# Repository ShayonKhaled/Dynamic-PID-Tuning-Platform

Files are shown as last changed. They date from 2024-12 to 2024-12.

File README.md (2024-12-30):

# **Dynamic PID Tuning Platform**


## **Overview**

The **Dynamic PID Tuning Platform** is a user-friendly test rig built to make PID tuning easier for robotics projects. It’s specifically designed for tuning the PID settings of DJI Robomaster M3508 P19 motors, which are controlled using C620 ESCs via the CAN protocol.

With this platform, you can easily adjust PID parameters and monitor real-time feedback on setpoints, motor speed (RPM), and control outputs. The data is displayed on an onboard LCD and can also be visualized using an external Python-based software for more detailed analysis.

Watch this video to see it in action:

https://github.com/user-attachments/assets/ace8c13b-92a7-4c02-9562-aeda0b1e9ec8

---

## **Features**
- **Real-time PID Tuning:** Adjust P, I, and D values using rotary encoders.
- **CAN Bus Communication:** Sends control data to Robomaster C620 ESCs.
- **Live Monitoring:** Displays motor speed, setpoint, and PID outputs on a 20x4 LCD display.
- **External Visualization:** Outputs CSV-formatted data to a Python-based GUI for graphing and analysis.

### **Limitations**
- At this time, the code supports controlling only **one motor** at a time.

---

## **Hardware Components**
- **Freenove ESP32 Dev Board** (or any ESP32 board)
- **Robomaster C620 ESC** and **M3508 P19 Motor**
- **MCP2515 CAN module**
- **KY-040 Rotary Encoders** (4x for P, I, D, and setpoint)
- **20x4 LCD Display** with I2C Backpack (PCF8574)

### **Recommended Wiring**
For easier connections, it is recommended to use a Freenove ESP32 breakout board. You can also build the circuit on a breadboard if necessary. Using an external 5V power source for peripherals is highly recommended.

---

## **Pin Connections**

| **Component** | **Pin on Component** | **Pin on ESP32**  |
|---|---|---|
| MCP2515 CAN Module | CS | GPIO 5 |
| | INT | GPIO 15 |
| KY-040 Encoder (P) | CLK | GPIO 35 |
| | DT | GPIO 32 |
| KY-040 Encoder (I) | CLK | GPIO 25 |
| | DT | GPIO 33 |
| KY-040 Encoder (D) | CLK | GPIO 27 |
| | DT | GPIO 26 |
| KY-040 Encoder (Setpoint) | CLK | GPIO 39 |
| | DT | GPIO 34 |
| 20x4 LCD Display with I2C | SDA | GPIO 21 |
| | SCL | GPIO 22 |

---

## **Software Features**
### **ESP32 Firmware**
- Written in Arduino framework using PlatformIO.
- Implements PID control logic with:
  - Adjustable P, I, D values using rotary encoders.
  - Real-time CAN communication with the C620 ESC.
  - CSV-formatted serial data output for visualization.
  


### **Python Visualization Tool**
- Plots real-time graphs of:
  - Motor RPM
  - Setpoint
  - PID output
- Provides GUI controls for serial port selection.

---

## **Setup Instructions**
1. **Hardware Setup:**
   - Connect all components as per the pin connections table.
   - Use an external 5V power source for the MCP2515 module and the LCD to ensure stability.

2. **Software Setup:**
   - Install PlatformIO extension on Visual Studio Code if you haven't already.
   - Clone this repository:
     ```bash
     git clone https://github.com/ShayonKhaled/Dynamic-PID-Tuning-Platform.git
     ```
   - Open the project in PlatformIO and upload the firmware to your ESP32.

3. **Python Visualization:**
   - Install required Python libraries:
     ```bash
     pip install matplotlib pyserial tkinter
     ```
   - Run the Python script for real-time graphing:
     ```bash
     python3 pidVisualizer.py
     ```
   - Select the serial port of your ESP32 from the drop down menu and hit the connect button. The ESP32 must be connected to your computer.
   
   

  

---

## **Notes**
- **Power Supply:** Avoid drawing power for the MCP2515 and LCD display directly from the ESP32. Use a separate 5V supply to prevent voltage drops and ensure reliable operation.
- **Freenove ESP32 Breakout Board:** The breakout board simplifies wiring but is not mandatory.

---

## **Building the DIN Rail Test Rack**

To house the components and provide a modular design, I used **4X 250mm DIN rails** to build the test rack. The stands for the rails were designed by **PlasticXYZ** and can be found here: [DIN Rail Test Rack Stands by PlasticXYZ](https://www.printables.com/model/150786-din-rail-test-rack).

### **Custom Mount Designs**
I designed custom mounts for the following components:
- **Freenove ESP32 Breakout Board**
- **MCP2515 CAN Transceiver Module**
- **Rotary Encoders**
- **20x4 LCD**

These designs are included in the **"3D Printables"** folder in both **.STL** and **.STEP** formats. You can choose to:
1. **Bolt the mounts directly onto the DIN rail**, or
2. **Use DIN clips** (designed by PlasticXYZ) to attach them. The DIN clips can be mounted or unmounted easily from the DIN rails. You can find the DIN clips design here: [DIN Rail Clip by PlasticXYZ](https://www.printables.com/model/161740-din-rail-clip).

### **Mounting Specifications**
- **Mounting Holes:** 18mm apart. These can be modified using the provided `.STEP` files if needed.
- **Fasteners Used:**
  - **Modules:** Mounted with self-tapping screws.
  - **DIN Clips:** Mounted with M3 bolts (6mm length).
- **No Heat Press Inserts:** The mounts were specifically designed for simplicity, and all components are secured with self-tapping screws or bolts.

This setup provides a sturdy, modular, and customizable framework for the PID tuning platform, making it easy to assemble, modify, and expand as needed.

## **License**
This project is licensed under the GNU General Public License v3.0 License. See the [LICENSE](LICENSE) file for details.

---

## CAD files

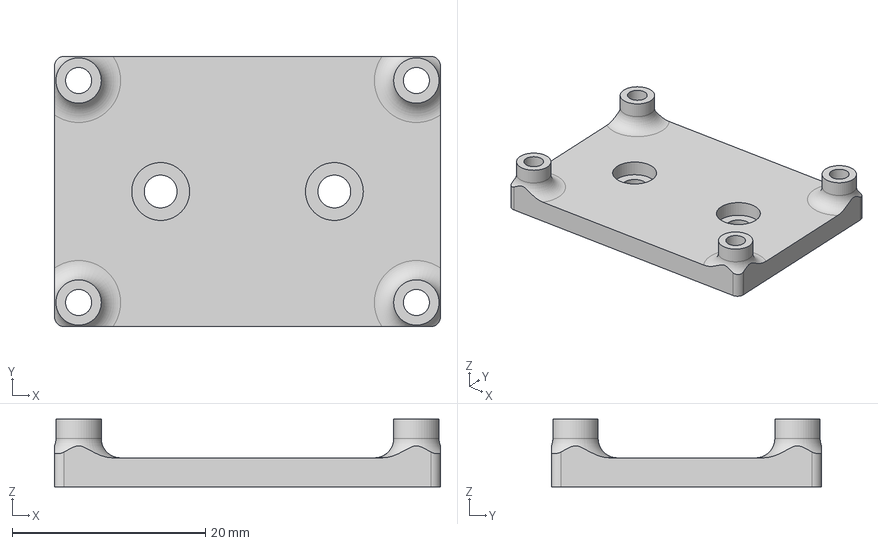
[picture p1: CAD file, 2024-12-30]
3D Printables/STEP files/MCP2515 CAN DIN Mount.step
40.0 x 28.0 x 7.00 mm

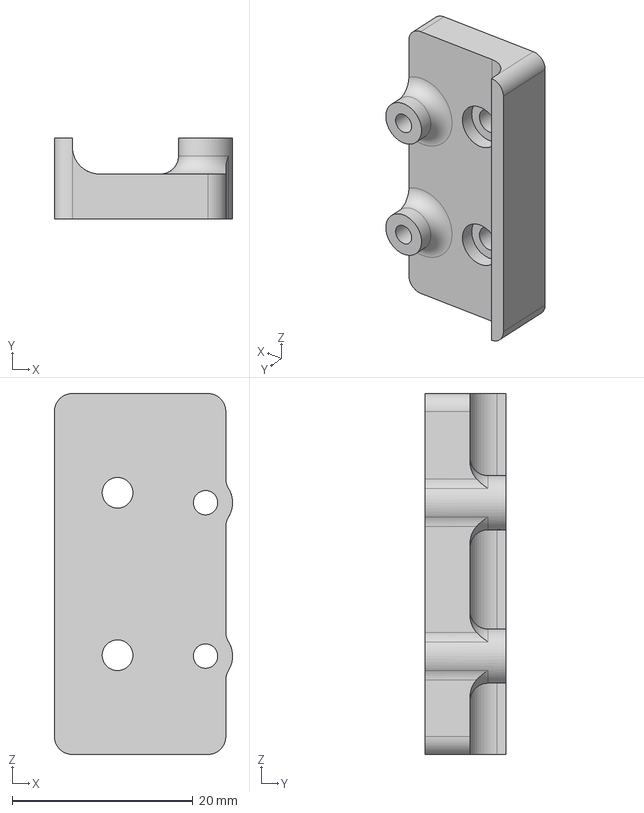
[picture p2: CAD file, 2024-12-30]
3D Printables/STEP files/KY-040 Rotary Encoder DIN Mount.step
19.7 x 9.00 x 40.0 mm

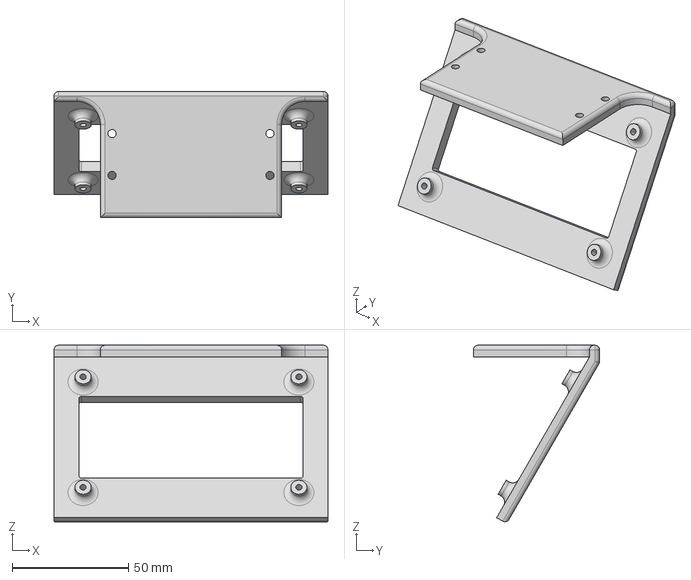
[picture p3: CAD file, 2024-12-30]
3D Printables/STEP files/2004 LCD Mount DIN Mount.step
118.0 x 54.3 x 76.0 mm

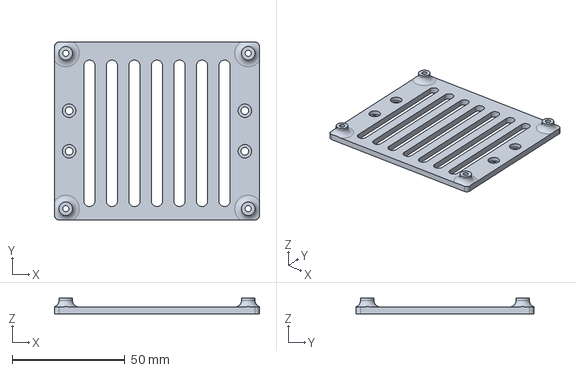
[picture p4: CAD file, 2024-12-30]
3D Printables/STEP files/Freenove ESP32 DIN Mount.step
91.0 x 79.0 x 7.05 mm

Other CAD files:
3D Printables/STL Files/2004 LCD Mount DIN Mount.stl
3D Printables/STL Files/Freenove ESP32 DIN Mount.stl
3D Printables/STL Files/KY-040 Rotary Encoder DIN Mount.stl
3D Printables/STL Files/MCP2515 CAN DIN Mount.stl

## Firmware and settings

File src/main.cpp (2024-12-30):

#include "config.h"
#include "encoder.h"
#include "lcd_control.h"
#include "can_comm.h"
#include "pid_control.h"

#define pidStepSize 0.001
#define setpointStepSize 500

void setup()
{
    Serial.begin(115200);

    initLCD();
    initCAN();


    pinMode(encoderPA, INPUT_PULLUP);
    pinMode(encoderPB, INPUT_PULLUP);
    pinMode(encoderIA, INPUT_PULLUP);
    pinMode(encoderIB, INPUT_PULLUP);
    pinMode(encoderDA, INPUT_PULLUP);
    pinMode(encoderDB, INPUT_PULLUP);
    pinMode(encoderSetpointA, INPUT_PULLUP);
    pinMode(encoderSetpointB, INPUT_PULLUP);
    pinMode(canInt, INPUT);

    attachInterrupt(digitalPinToInterrupt(encoderPA), handlePEncoder, CHANGE);
    attachInterrupt(digitalPinToInterrupt(encoderPB), handlePEncoder, CHANGE);
    attachInterrupt(digitalPinToInterrupt(encoderIA), handleIEncoder, CHANGE);
    attachInterrupt(digitalPinToInterrupt(encoderIB), handleIEncoder, CHANGE);
    attachInterrupt(digitalPinToInterrupt(encoderDA), handleDEncoder, CHANGE);
    attachInterrupt(digitalPinToInterrupt(encoderDB), handleDEncoder, CHANGE);
    attachInterrupt(digitalPinToInterrupt(encoderSetpointA), handleSetpointEncoder, CHANGE);
    attachInterrupt(digitalPinToInterrupt(encoderSetpointB), handleSetpointEncoder, CHANGE);


    delay(1000);
    lcd.clear();
    lcd.setCursor(1, 1);
    lcd.print("Dynamic PID Tuning");
    lcd.setCursor(6, 2);
    lcd.print("Platform");
    delay(2000);
    lcd.clear();
}

void loop()
{
    static unsigned long lastUpdate = 0;
    unsigned long currentMillis = millis();

    
    // Read from the designated kP kI kD encoders and multiply them by pidStepSize to allow smaller steps
    pVal = P_count * pidStepSize;
    iVal = I_count * 0.0001;
    dVal = D_count * pidStepSize;
    setpointVal = constrain(setpoint_count * setpointStepSize, 0, 9000);

    short rpm = receiveRPM(); //receive RPM from the encoder of the motor
    currentSpeed = (rpm == 0) ? 0 : rpm; //if RPM is not 0, copy the value to currentSpeed

    float controlOutput = computePID(setpointVal, currentSpeed); //Run the setpoint and current speed through the contrl loop

    short controlSpeed = (short)controlOutput; // Cast to short for CAN message

    //sending higher order byte and lower order byte of the speed to the first motor on the CAN Bus.
    byte data[8] = {controlSpeed >> 8, controlSpeed, 0x00, 0x00, 0x00, 0x00, 0x00, 0x00}; 
    sendCANMessage(0x200, data, 8); //message ID for the first 4 motors is 0x200 according to the DJI C620 manual



    // sending the data in CSV format for the Python program to read
    Serial.print("Setpoint:");
    Serial.print(setpointVal); 
    Serial.print(",RPM:");
    Serial.print(currentSpeed); 
    Serial.print(",PID:");
    Serial.print(controlOutput);
    Serial.print(",P:");
    Serial.print(pVal);
    Serial.print(",I:");
    Serial.print(iVal); 
    Serial.print(",D:");
    Serial.println(dVal); 

    if (currentMillis - lastUpdate >= 100)
    {
        lastUpdate = currentMillis;
        updateLCD(); // update LCD every 100 milliseconds
    }
}

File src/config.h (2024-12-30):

#ifndef CONFIG_H
#define CONFIG_H

#include <Wire.h>
#include <LiquidCrystal_I2C.h>
#include <Arduino.h>

// LCD configuration
#define lcdColumn 20
#define lcdRow 4
#define lcdAddress 0x27

// Declare the LCD object for global access
extern LiquidCrystal_I2C lcd;

// Encoder pin definitions
#define encoderPA 35
#define encoderPB 32
#define encoderIA 25
#define encoderIB 33
#define encoderDA 27
#define encoderDB 26
#define encoderSetpointA 39
#define encoderSetpointB 34


#define canCsPin 5
#define canInt 15


// Declare global variables
extern volatile int P_count, I_count, D_count, setpoint_count;
extern volatile int P_lastState, I_lastState, D_lastState, setpoint_lastState;
extern short currentSpeed;

extern float pVal, iVal, dVal, setpointVal;
extern bool showText;

#endif 

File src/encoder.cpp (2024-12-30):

#include "encoder.h"
#include "config.h"

void IRAM_ATTR handlePEncoder()
{
  // read the state of the encoder pins
  int A = digitalRead(encoderPA);
  int B = digitalRead(encoderPB);
  int currentState = (A << 1) | B;

  // check if the encoder is rotating clockwise
  if ((P_lastState == 0b00 && currentState == 0b01) ||
      (P_lastState == 0b01 && currentState == 0b11) ||
      (P_lastState == 0b11 && currentState == 0b10) ||
      (P_lastState == 0b10 && currentState == 0b00))
  {
    P_count++;
  }
  // check if the encoder is rotating counterclockwise
  else if ((P_lastState == 0b00 && currentState == 0b10) ||
           (P_lastState == 0b10 && currentState == 0b11) ||
           (P_lastState == 0b11 && currentState == 0b01) ||
           (P_lastState == 0b01 && currentState == 0b00))
  {
    P_count--;
  }
  // update the last state
  P_lastState = currentState;
}

void IRAM_ATTR handleIEncoder()
{
  // read the state of the encoder pins
  int A = digitalRead(encoderIA);
  int B = digitalRead(encoderIB);
  int currentState = (A << 1) | B;

  // check if the encoder is rotating clockwise
  if ((I_lastState == 0b00 && currentState == 0b01) ||
      (I_lastState == 0b01 && currentState == 0b11) ||
      (I_lastState == 0b11 && currentState == 0b10) ||
      (I_lastState == 0b10 && currentState == 0b00))
  {
    I_count++;
  }
  // check if the encoder is rotating counterclockwise
  else if ((I_lastState == 0b00 && currentState == 0b10) ||
           (I_lastState == 0b10 && currentState == 0b11) ||
           (I_lastState == 0b11 && currentState == 0b01) ||
           (I_lastState == 0b01 && currentState == 0b00))
  {
    I_count--;
  }
  // update the last state
  I_lastState = currentState;
}

void IRAM_ATTR handleDEncoder()
{
  // read the state of the encoder pins
  int A = digitalRead(encoderDA);
  int B = digitalRead(encoderDB);
  int currentState = (A << 1) | B;

  // check if the encoder is rotating clockwise
  if ((D_lastState == 0b00 && currentState == 0b01) ||
      (D_lastState == 0b01 && currentState == 0b11) ||
      (D_lastState == 0b11 && currentState == 0b10) ||
      (D_lastState == 0b10 && currentState == 0b00))
  {
    D_count++;
  }
  // check if the encoder is rotating counterclockwise
  else if ((D_lastState == 0b00 && currentState == 0b10) ||
           (D_lastState == 0b10 && currentState == 0b11) ||
           (D_lastState == 0b11 && currentState == 0b01) ||
           (D_lastState == 0b01 && currentState == 0b00))
  {
    D_count--;
  }
  // update the last state
  D_lastState = currentState;
}

void IRAM_ATTR handleSetpointEncoder()
{
    // read the state of the encoder pins
    int A = digitalRead(encoderSetpointA);
    int B = digitalRead(encoderSetpointB);
    int currentState = (A << 1) | B;

    // check if the encoder is rotating clockwise
    if ((setpoint_lastState == 0b00 && currentState == 0b01) ||
        (setpoint_lastState == 0b01 && currentState == 0b11) ||
        (setpoint_lastState == 0b11 && currentState == 0b10) ||
        (setpoint_lastState == 0b10 && currentState == 0b00))
    {
        // increment only if below the upper limit
        if (setpoint_count < 9000)
        {
            setpoint_count++;
        }
        else {return;}
    }
    // check if the encoder is rotating counterclockwise
    else if ((setpoint_lastState == 0b00 && currentState == 0b10) ||
             (setpoint_lastState == 0b10 && currentState == 0b11) ||
             (setpoint_lastState == 0b11 && currentState == 0b01) ||
             (setpoint_lastState == 0b01 && currentState == 0b00))
    {
        // decrement only if above the lower limit
        if (setpoint_count > 0)
        {
            setpoint_count--;
        }
        else {return;}
    }

    // update the last state
    setpoint_lastState = currentState;
}

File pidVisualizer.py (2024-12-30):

import matplotlib
matplotlib.use("TkAgg")  # Use TkAgg backend for compatibility on macOS

import serial
import serial.tools.list_ports
import matplotlib.pyplot as plt
from matplotlib.animation import FuncAnimation
from matplotlib.backends.backend_tkagg import FigureCanvasTkAgg
import tkinter as tk
from tkinter import StringVar, OptionMenu

# Global variables for serial connection
ser = None
baudRate = 115200
dataPoints = 100  # Number of points to display on the graph

# Data storage
rpmData = []
setpointData = []
pidData = []

# Labels for real-time values
pValue = None
iValue = None
dValue = None
setpointValue = None
currentSpeed = None
controlOutput = None

# Function to list available serial ports
def getSerialPorts():
    ports = serial.tools.list_ports.comports()
    return [port.device for port in ports]

# Function to start the serial connection
def startConnection(selectedPort, statusLabel, disconnectButton):
    global ser
    try:
        ser = serial.Serial(selectedPort, baudRate, timeout=1)
        statusLabel.config(text=f"Connected to {selectedPort}", fg="lightgreen")
        disconnectButton.config(state="normal")  # Enable the disconnect button
    except Exception as e:
        statusLabel.config(text=f"Failed to connect: {e}", fg="red")

# Function to disconnect the serial connection
def disconnectConnection(statusLabel, disconnectButton):
    global ser
    if ser and ser.is_open:
        ser.close()
        ser = None
        statusLabel.config(text="Disconnected", fg="red")
        disconnectButton.config(state="disabled")  # Disable the disconnect button

# Function to update the graph and all displayed values
def updateGraph(frame, pValue, iValue, dValue, setpointValue, currentSpeed, controlOutput):
    global rpmData, setpointData, pidData, ser

    if ser and ser.is_open:
        try:
            line = ser.readline().decode('utf-8').strip()
            if line:
                # Parse data (e.g., Setpoint:2000,RPM:1500,PID:500.0,P:0.5,I:0.01,D:0.001)
                data = {}
                for pair in line.split(','):
                    key, value = pair.split(':')
                    data[key] = float(value)

                # Update all displayed values
                pValue.set(f"P: {data['P']:.2f}")
                iValue.set(f"I: {data['I']:.2f}")
                dValue.set(f"D: {data['D']:.2f}")
                setpointValue.set(f"Setpoint: {data['Setpoint']:.0f}")
                currentSpeed.set(f"Speed: {data['RPM']:.0f}")
                controlOutput.set(f"Output: {data['PID']:.2f}")

                # Append data to lists
                rpmData.append(data['RPM'])
                setpointData.append(data['Setpoint'])
                pidData.append(data['PID'])

                # Keep data list lengths consistent
                if len(rpmData) > dataPoints:
                    rpmData.pop(0)
                    setpointData.pop(0)
                    pidData.pop(0)

                # Update plots
                rpmLine.set_ydata(rpmData)
                setpointLine.set_ydata(setpointData)
                pidLine.set_ydata(pidData)
                rpmLine.set_xdata(range(len(rpmData)))
                setpointLine.set_xdata(range(len(setpointData)))
                pidLine.set_xdata(range(len(pidData)))

                ax.relim()
                ax.autoscale_view()
        except Exception as e:
            print(f"Error reading data: {e}")

# Create the main application
def createApp():
    global rpmLine, setpointLine, pidLine, ax

    # Initialize the Tkinter root
    root = tk.Tk()
    root.title("Dynamic PID Tuning Platform")

    # Apply dark mode
    root.configure(bg="black")

    # Create StringVars after the root is initialized
    global pValue, iValue, dValue, setpointValue, currentSpeed, controlOutput
    pValue = StringVar(root)
    iValue = StringVar(root)
    dValue = StringVar(root)
    setpointValue = StringVar(root)
    currentSpeed = StringVar(root)
    controlOutput = StringVar(root)

    # Set default values
    pValue.set("P: 0.0")
    iValue.set("I: 0.0")
    dValue.set("D: 0.0")
    setpointValue.set("Setpoint: 0")
    currentSpeed.set("Speed: 0")
    controlOutput.set("Output: 0.0")

    # Create a frame for real-time values
    valueFrame = tk.Frame(root, bg="black")
    valueFrame.pack(side=tk.TOP, fill=tk.X)

    # Add labels for P, I, D, Setpoint, Speed, and Output
    fontSettings = ("Helvetica", 30)  # Bigger font size for better visibility
    tk.Label(valueFrame, textvariable=pValue, font=fontSettings, fg="white", bg="black").pack(side=tk.LEFT, padx=10, pady=10)
    tk.Label(valueFrame, textvariable=iValue, font=fontSettings, fg="white", bg="black").pack(side=tk.LEFT, padx=10, pady=10)
    tk.Label(valueFrame, textvariable=dValue, font=fontSettings, fg="white", bg="black").pack(side=tk.LEFT, padx=10, pady=10)
    tk.Label(valueFrame, textvariable=setpointValue, font=fontSettings, fg="white", bg="black").pack(side=tk.LEFT, padx=10, pady=10)
    tk.Label(valueFrame, textvariable=currentSpeed, font=fontSettings, fg="white", bg="black").pack(side=tk.LEFT, padx=10, pady=10)
    tk.Label(valueFrame, textvariable=controlOutput, font=fontSettings, fg="white", bg="black").pack(side=tk.LEFT, padx=10, pady=10)

    # Create a matplotlib figure with dark theme
    plt.style.use("dark_background")
    fig, ax = plt.subplots()
    rpmLine, = ax.plot([], [], label='RPM', color='cyan')
    setpointLine, = ax.plot([], [], label='Setpoint', color='lime')
    pidLine, = ax.plot([], [], label='PID Output', color='magenta')

    ax.set_title("Motor Data", color="white")
    ax.set_xlabel("Time", color="white")
    ax.set_ylabel("Values", color="white")
    ax.tick_params(colors="white")
    ax.legend(facecolor="black", edgecolor="white")

    # Embed the matplotlib figure in the Tkinter window
    canvas = FigureCanvasTkAgg(fig, master=root)
    canvas.get_tk_widget().pack(side=tk.TOP, fill=tk.BOTH, expand=True)

    # Create a frame for the dropdown and status
    controlFrame = tk.Frame(root, bg="black")
    controlFrame.pack(side=tk.BOTTOM, fill=tk.X)

    # Dropdown menu for serial ports
    availablePorts = getSerialPorts()
    selectedPort = StringVar(root)
    if availablePorts:
        selectedPort.set(availablePorts[0])  # Default to the first available port
    else:
        selectedPort.set("No ports available")
        selected_port = StringVar(value=available_ports[0])
    tk.Label(controlFrame, text="Select Serial Port:", fg="white", bg="black").pack(side=tk.LEFT, padx=5, pady=10)
    portDropdown = OptionMenu(controlFrame, selectedPort, *availablePorts)
    portDropdown.config(bg="black", fg="white")
    portDropdown.pack(side=tk.LEFT, padx=5, pady=10)

    # Status label
    statusLabel = tk.Label(controlFrame, text="Not connected", fg="red", bg="black")
    statusLabel.pack(side=tk.LEFT, padx=5, pady=10)
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

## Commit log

2024-12-30 Adding 3D Print Files
    [2004 LCD Mount DIN Mount.step, 2004 LCD Mount DIN Mount.stl, Freenove ESP32 DIN Mount.step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]
2024-12-30 made changes
    [2004 LCD Mount DIN Mount.step, 2004 LCD Mount DIN Mount.stl, Freenove ESP32 DIN Mount.step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]
